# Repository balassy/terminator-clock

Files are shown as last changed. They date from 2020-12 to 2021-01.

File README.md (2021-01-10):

# Terminator Clock (T-800 Eye Mechanism Prototype)

An ESP8266-controlled NTP-based alarm clock that looks like a T-800 eye mechanism prototype with a React configuration UI.

> I decided to stop working on this project, so don't expect any update here. In its current state this is more like a proof of concept together with my [Arduino MP3 Alarm Clock](https://github.com/balassy/arduino-mp3-alarm-clock) project. Check the `_Photos` folder to see the current status of this project.

## Yet Another T-800 Eye Model?

I created this project, because:
- I wanted moving T-800 eye mechanism with a working LED in it.
- I wanted to control it with a microcontroller to add additional features (sounds, sensors etc.).
- I wanted to experiment with ball joints created by FDM printers.
- I wanted to build a web UI for ESP8266 with React.

Lessons learned:
- Creating ball joints on FDM printers is possible, but needs sanding and experimenting to get the perfect snap fit.
- Servos do a homing when they powered up. This means the SG90 quickly jumps back to its home position then the device is turned on. This quick jump can shake the snap fit joints apart.
- The [esp8266-react](https://github.com/rjwats/esp8266-react) is a good starting point, though the build task is quite slow.
- When you import an existing model into Fusion 360 take your time to aligne it perfectly with your existing reference faces and axes (e.g. origin). A fraction of a millimeter error can be magnified in a few centimeters apart and cause misaligned constraints or break the symmetry.

You can check how the eye moves in [this Youtube video](https://www.youtube.com/watch?v=Tz13K7Pk3AE):

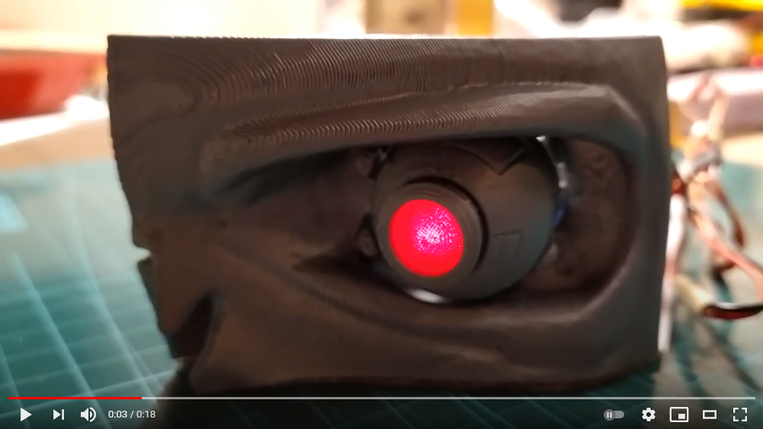
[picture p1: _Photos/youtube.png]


## Hardware

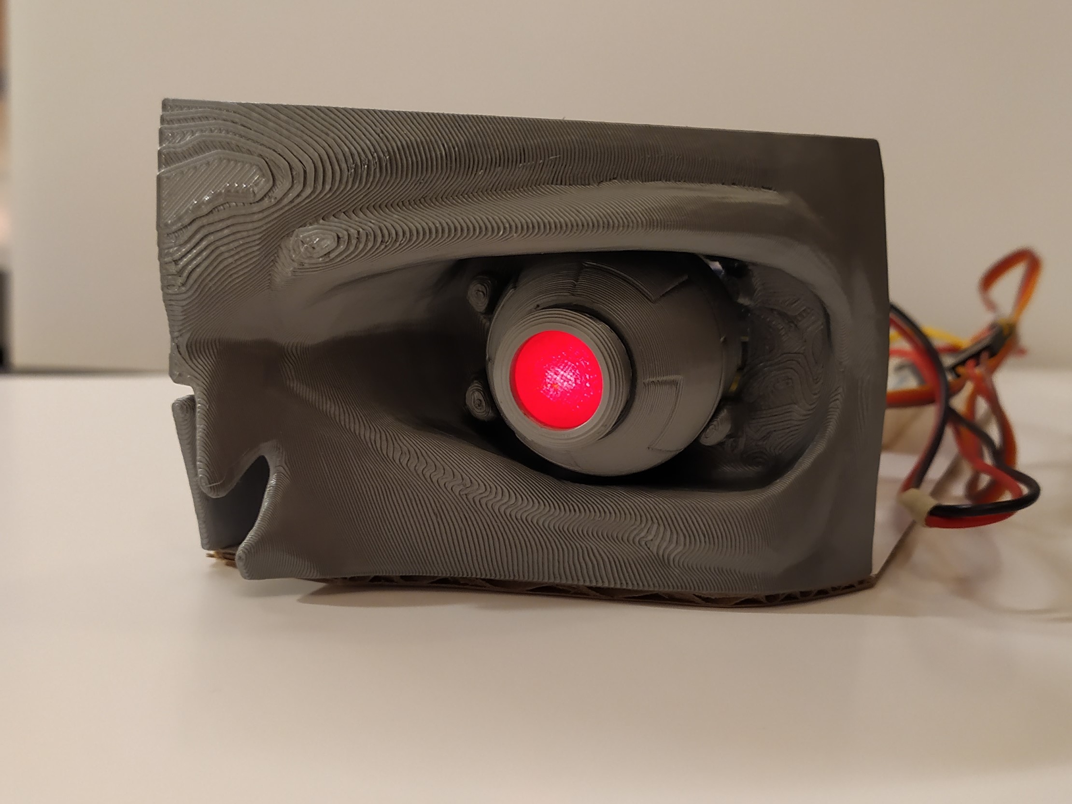
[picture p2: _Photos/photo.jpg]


Parts:
- 1× Wemos D1 Mini
- 2× SG90 servo motor
- 1× 5mm red LED
- 1× 100Ω resistor

Wiring:
1. Connect the LED to 3.3V and GND.
2. Connect the vertical servo to 5V, GND and D3.
3. Connect the horizontal servo to 5V, GNd and D0.

## Software

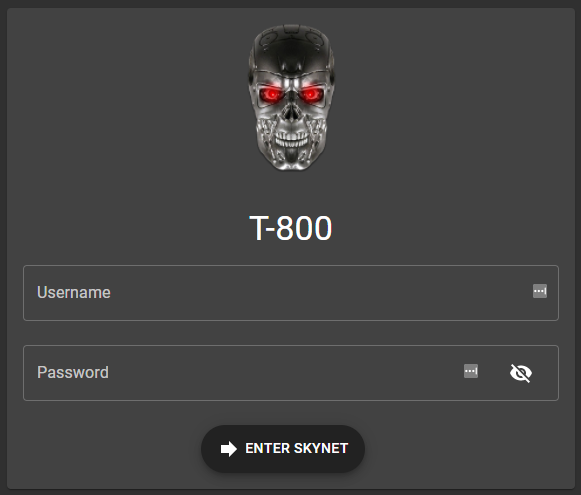
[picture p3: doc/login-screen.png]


This project relies on [Platform IO](https://platformio.org/) so first you have to install that.

The web interface is built with [esp8266-react](https://github.com/rjwats/esp8266-react) the README of that project contains a lot of details about how this project is structured.

The Git history of this repository shows how I rebranded it to T-800 style.

## 3D Printed Parts

You can find the 3D printable STL files in the `_3D-Print` folder.

I designed the model with Fusion 360 and also shared the source files in case you want to further enhance them. I shared the same files also on [Thingiverse](https://www.thingiverse.com/thing:4716967).

The eyeball, iris and pupil is based on [Metalnat's Terminator Eye model](https://www.thingiverse.com/thing:984200) on Thingiverse.

## About the author

This project was created by [György Balássy](https://linkedin.com/in/balassy).

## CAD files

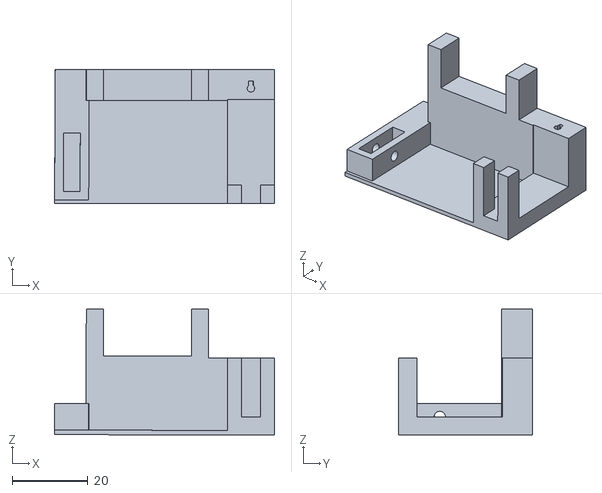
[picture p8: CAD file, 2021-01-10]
_3D-Print/v70 MotorBase.stl
58.0 x 35.4 x 33.2

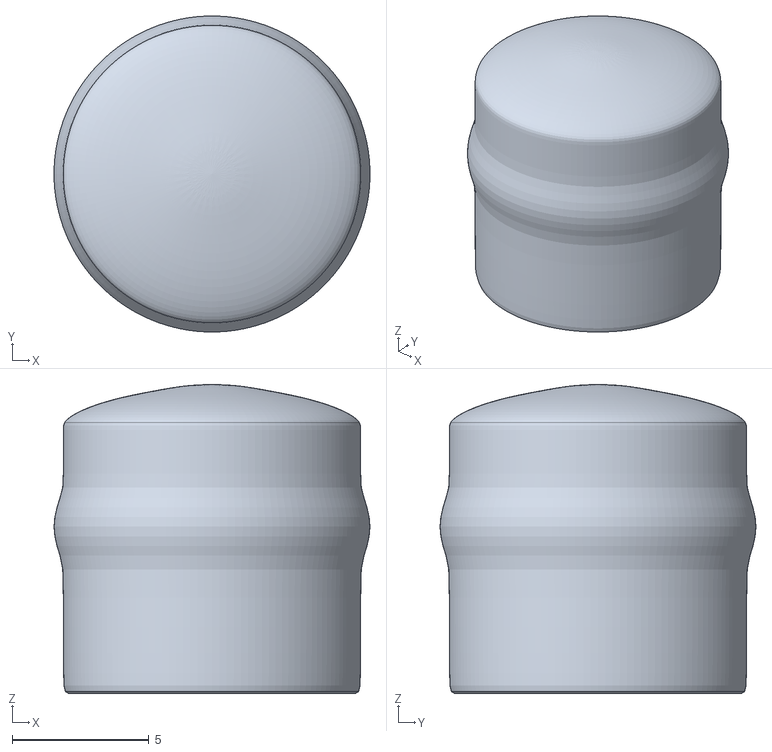
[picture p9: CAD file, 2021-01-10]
_3D-Print/Thing 984200 - Pupil.stl
11.5 x 11.5 x 11.3

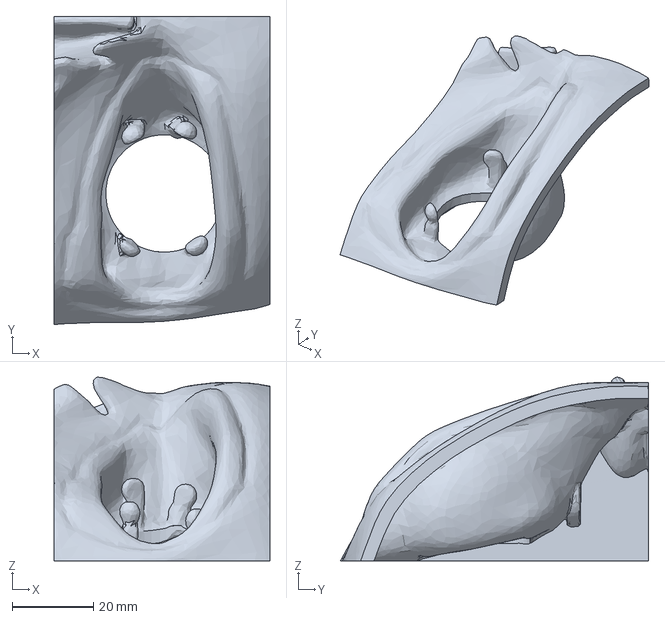
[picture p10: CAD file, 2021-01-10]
_3D-Print/v70 Skull repaired with support blocker.3mf
53.3 x 76.1 x 45.4 mm

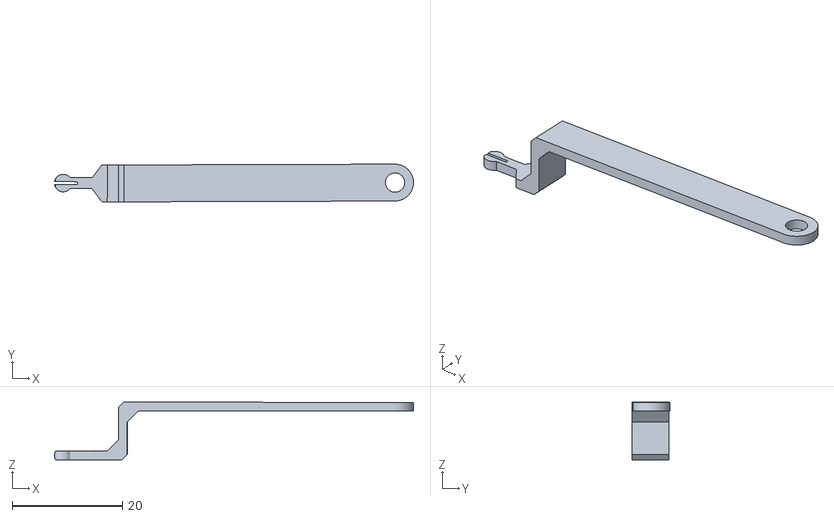
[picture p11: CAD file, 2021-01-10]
_3D-Print/v70 Horizontal Connector.stl
65.1 x 6.85 x 10.5

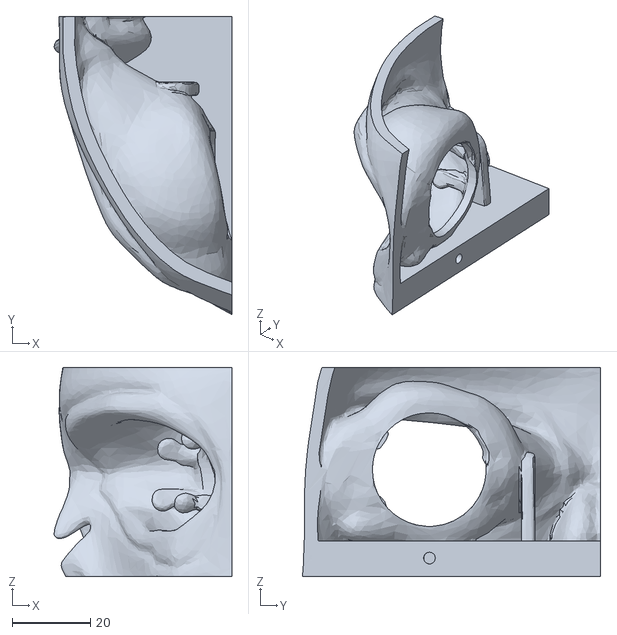
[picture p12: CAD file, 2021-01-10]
_3D-Print/v70 Skull.stl
45.4 x 76.1 x 53.3

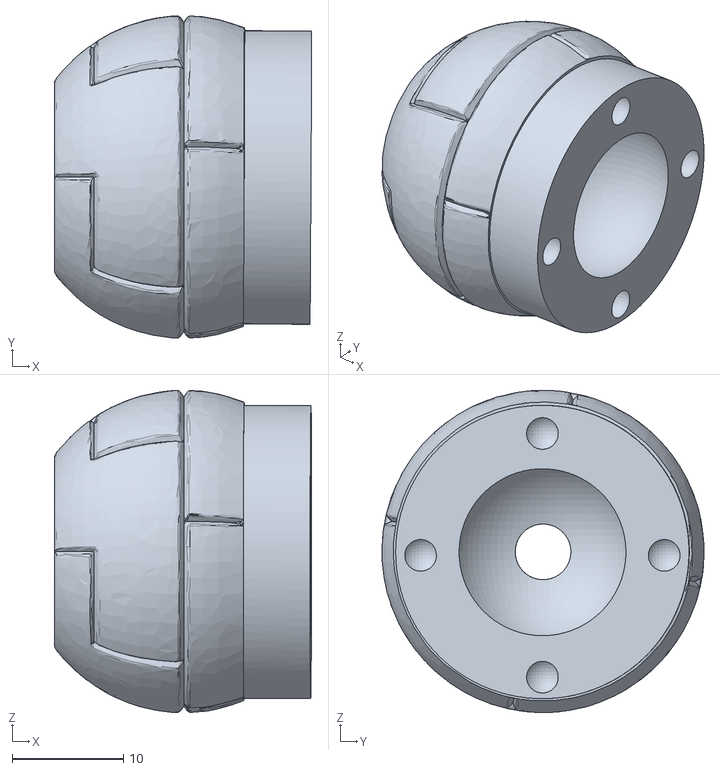
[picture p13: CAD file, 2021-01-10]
_3D-Print/v70 Eye ball.stl
23.1 x 28.9 x 28.9

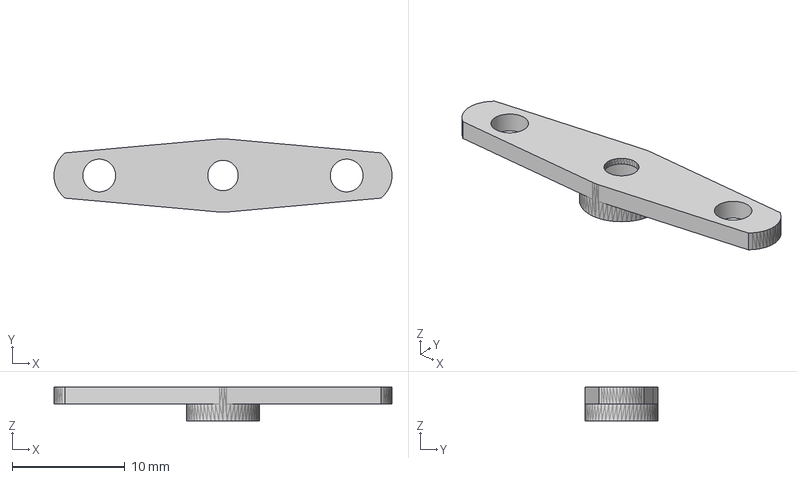
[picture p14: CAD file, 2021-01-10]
_3D-Print/Servo Arm v8.step
29.9 x 6.50 x 3.00 mm

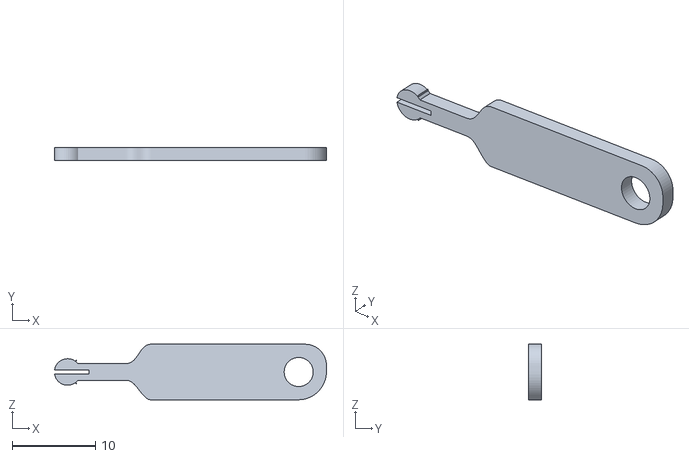
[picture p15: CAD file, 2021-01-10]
_3D-Print/v70 Vertical Connector.stl
32.8 x 1.60 x 6.70

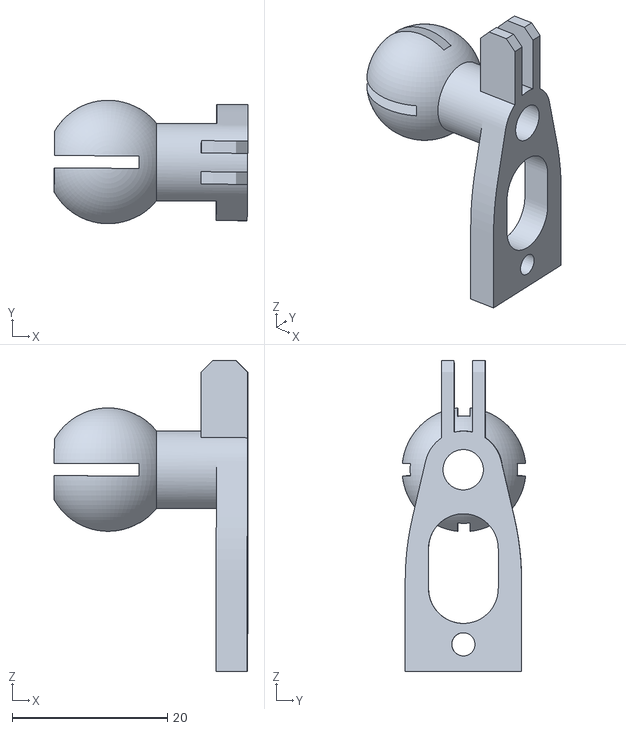
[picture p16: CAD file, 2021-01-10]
_3D-Print/v70 Ball Joint.stl
25.0 x 15.9 x 40.1

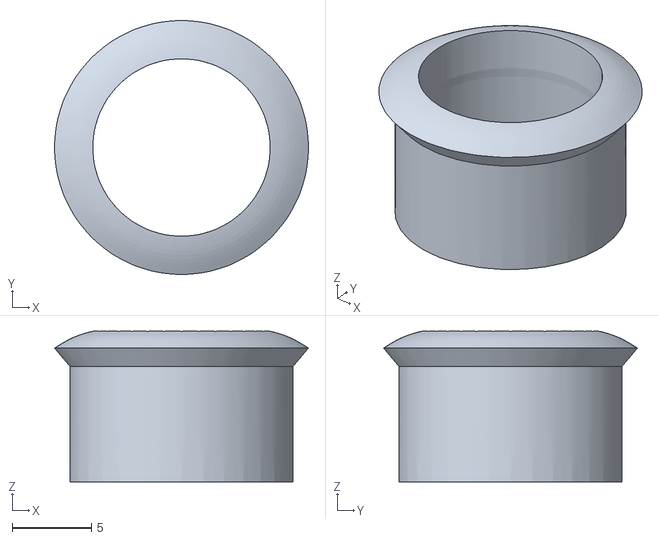
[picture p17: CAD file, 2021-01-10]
_3D-Print/Thing 984200 - Iris_V2.stl
16.1 x 16.1 x 9.53

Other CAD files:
_3D-Print/v70 Skull repaired.3mf
_3D-Print/v70 Servo Arm v8.stl
_3D-Print/Servo Arm v8.f3d

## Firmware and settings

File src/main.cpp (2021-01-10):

#include <ESP8266React.h>
#include <LightMqttSettingsService.h>
#include <LightStateService.h>

#include "sounds/SoundsStateService.h"
#include "play/PlayStateService.h"

#include "speed-servo.h"

#define SERIAL_BAUD_RATE 115200

AsyncWebServer server(80);
ESP8266React esp8266React(&server);
LightMqttSettingsService lightMqttSettingsService =
    LightMqttSettingsService(&server, esp8266React.getFS(), esp8266React.getSecurityManager());
LightStateService lightStateService = LightStateService(&server,
                                                        esp8266React.getSecurityManager(),
                                                        esp8266React.getMqttClient(),
                                                        &lightMqttSettingsService);

SoundsStateService soundsStateService = SoundsStateService(&server,
                                                           esp8266React.getSecurityManager(),
                                                           esp8266React.getFS());

PlayStateService playStateService = PlayStateService(&server, esp8266React.getSecurityManager());

SpeedServo verticalServo;
SpeedServo horizontalServo;

void setupServos() {
  verticalServo.attach(D3);
  verticalServo.moveSlowTo(0);
  verticalServo.moveSlowTo(30);
  verticalServo.moveSlowTo(15);
  verticalServo.moveSlowTo(30);
  verticalServo.moveSlowTo(0);
  verticalServo.moveSlowTo(15);

  horizontalServo.attach(D0);
  horizontalServo.moveSlowTo(0);
  horizontalServo.moveSlowTo(30);
  horizontalServo.moveSlowTo(15);
  horizontalServo.moveSlowTo(30);
  horizontalServo.moveSlowTo(0);
  horizontalServo.moveSlowTo(15);
}

void setup() {
  // start serial and filesystem
  Serial.begin(SERIAL_BAUD_RATE);
  Serial.println("Main setup started...");

  // start the framework and demo project
  esp8266React.begin();

  // load the initial light settings
  lightStateService.begin();

  soundsStateService.begin();
  playStateService.begin();

  // start the light service
  lightMqttSettingsService.begin();

  // start the server
  server.begin();

  setupServos();

  Serial.println("Main setup completed.");
}

void loop() {
  // run the framework's loop function
  esp8266React.loop();
}

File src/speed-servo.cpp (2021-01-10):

#include "speed-servo.h"

const int SLOW_MOVE_DELAY = 40;
const int FAST_MOVE_DELAY = 4;

void SpeedServo::attach(uint8_t pin) {
  _servo.attach(pin);
}

// Valid position: 0-180.
void SpeedServo::moveNowTo(int newPosition) {
  _lastPosition = newPosition;
  _servo.write(newPosition);
}

// Valid position: 0-180.
void SpeedServo::moveFastTo(int newPosition) {
  _moveTo(newPosition, FAST_MOVE_DELAY);
}

// Valid position: 0-180.
void SpeedServo::moveSlowTo(int newPosition) {
  _moveTo(newPosition, SLOW_MOVE_DELAY);
}

// Valid position: 0-180.
void SpeedServo::_moveTo(int newPosition, unsigned long stepDelay) {
  if(newPosition > _lastPosition) {
    for (int pos = _lastPosition; pos <= newPosition; pos++) {
      _servo.write(pos);
      delay(stepDelay);
    }
  } else {
    for (int pos = _lastPosition; pos >= newPosition; pos--) {
      _servo.write(pos);
      delay(stepDelay);
    }
  }

  _lastPosition = newPosition;
}

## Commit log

2020-12-11 feat: Alarms and Calibration page added to the left menu
2021-01-10 feat: basic servo tests at startup
2021-01-10 feat: 3D printable files
    [Servo Arm v8.f3d, Servo Arm v8.step, Thing 984200 - Iris_V2.stl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]
